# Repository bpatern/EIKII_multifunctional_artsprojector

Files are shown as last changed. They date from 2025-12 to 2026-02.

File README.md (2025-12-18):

**THE ORIGINAL GOAL**
**Make a 16mm film projector portable and playable like an instrument. Retrofit with a DC motor and LED lamp, controlled by ESP32 micro-controller.**
This project is part of [SPECTRAL Wandering Sounds and Images Seminar](https://www.mire-exp.org/evenement/spectral-wandering-sound-and-images/) in Nantes FR in 2023/2024, enabling film projection performances that explore itinerancy, nomadism, and adaptation to multiple environments.

----

Contents
======

---- 

 - [Bill of Materials (BOM)](https://www.filmlabs.org/wiki/en/meetings_projects/spectral/mire-wandering/wandering-16mmprojection/budget) (filmlabs.org) or [Google Sheets alternate](https://docs.google.com/spreadsheets/d/1z_asHddtIuv7a7RkZ9WCBqF81oMiJ9spwqh7lCQfW5E)
//self reminder to update w/ off the shelf parts and harvestable components
	
 - [Step-by-step Construction Guide](https://www.filmlabs.org/wiki/en/meetings_projects/spectral/mire-wandering/wandering-16mmprojection/construction_guide/start) for building and using the projector (filmlabs.org)
//break out into bulleted list with additional source for checking + installing LTC3780 and fan
//for non internal battery installations describe fitting of 20amp power supply
//describe optical printer dock and pros + cons
//describe stiffer motor mount construction from thick acrylic + pros and cons to using printed materials for this section

[openscad](https://github.com/z-l-p/film-projector-retrofit/tree/main/openscad)
----

 - Editable design files for 3D-printed parts (in OpenSCAD format)
 - new files are not made in openscad sorry

[projector\_code](https://github.com/bpatern/EIKII_multifunctional_artsprojector/tree/main/projector_code)
----

 - Code for the ESP32 micro-controller, raspberry Pi Pico 2W instruction parsing controller, and optical printer code that controls the projector (Arduino IDE)
 - optical printer functionality uses [Matt McWilliams' mCopy](https://github.com/sixteenmillimeter/mcopy) for sequencing. led support is enabled in sort of a hackneyed way, that currently only really works with my setup. id like to be able to have mCopy recognize the LED and its brightness control but I can't get mCopy and the led control scheme used in this code to shake hands. 

[stl](https://github.com/bpatern/EIKII_multifunctional_artsprojector/tree/main/stl)
----

 - Printable files for 3D-printed parts

closeup of lamp block
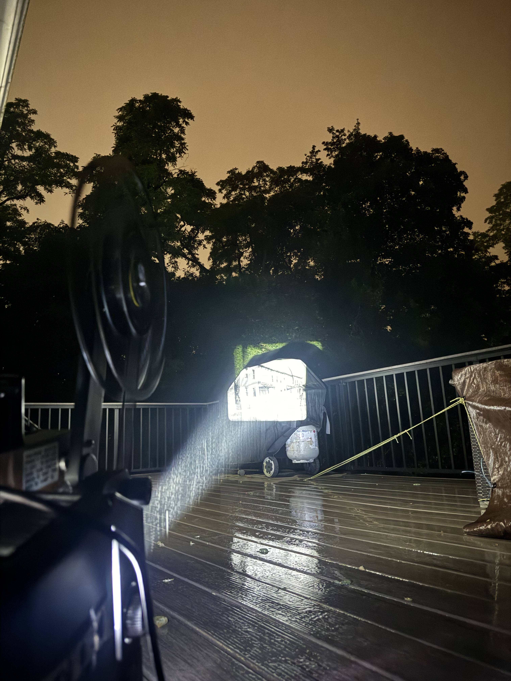
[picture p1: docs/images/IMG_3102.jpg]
projector in rain


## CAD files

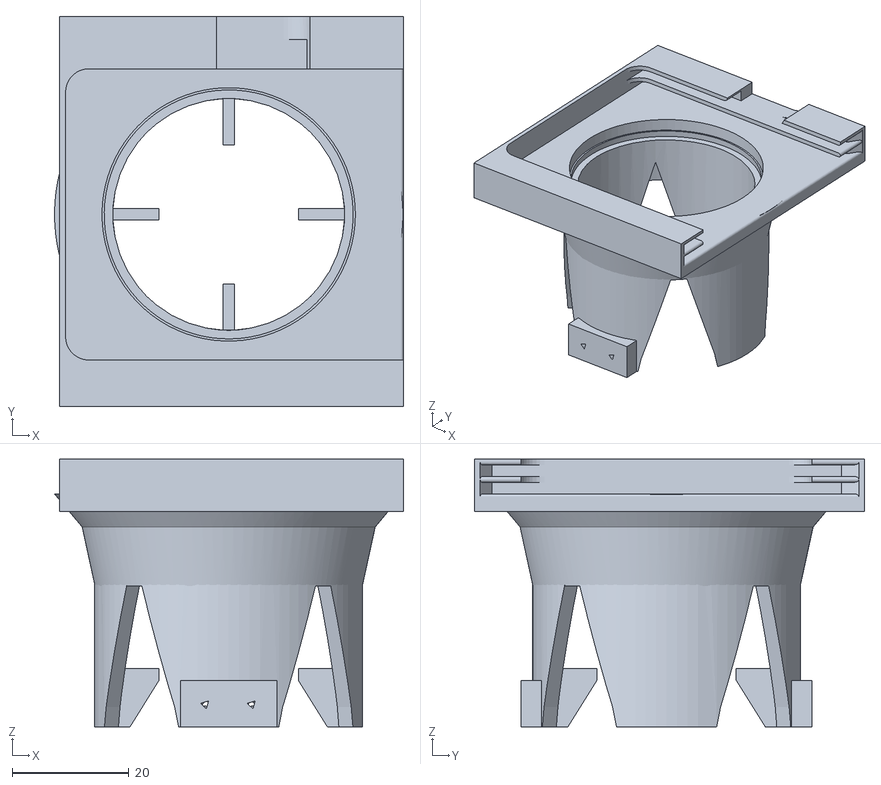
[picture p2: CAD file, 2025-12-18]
stl/led reflector holder for optical printer.stl
59.9 x 67.0 x 46.0

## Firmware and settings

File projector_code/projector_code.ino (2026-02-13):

//i've moved a lot around. biggest change i had to make was making certain variables global like those at the beginning of CalcFPS. if i didnt make this change i would get crashing if the projector was running for a Long Time. debug stated it was fetching a value before the value was even written. this is probably a result of additional tasks needing to happen during the main loop. splitting operations out to multicore would maybe help, or using the ESP32-s3 with additional SRAM

// ------------------------------------------
// SPECTRAL Wandering Sounds + Images Seminar
// ------------------------------------------
// Projector control software for ESP32 micro-controller
// On some 38pin ESP32 boards you need to press GPIO 0 [right] button each time you upload code. If so, solder 10uF cap between EN and GND to enable auto reset.
// Controlling Hobbywing "Quickrun Fusion SE" motor/ESC combo using ESP32 LEDC peripheral (using 16bit timer for extra resolution)
// Note: Hobbywing motor/esc needs to be programmed via "programming card" to disable braking, otherwise it will try to hold position when speed = 0
// (If you hack the ESC wiring according to our docs, you can program it with the ESCprogram() function instead of a programming card)
// "Digital shutter" is accomplished via AS5047 magnetic rotary encoder, setup via SPI registers and monitored via ABI quadrature pulses
// LED is dimmed via CC LED driver board with PWM input, driven by ESP32 LEDC (which causes slight PWM blinking artifacts at low brightness levels)
// Future option exists for current-controlled dimming (set LedDimMode=0): Perhaps a log taper digipot controlled via SPI? Probably can't dim below 20% though.


// TODO Nice but not essential:
// put UI vars in struct, in case we want to receive them from a remote ESP connected via radio
// if ESP32 Arduino core ever gets support for ledc output_invert method, we can simplify the ISR inverted condition

// Include the libraries
// NOTE: In 2023 this code was developed using the ESP32 Arduino core v2.0.9.
// When ESP32 Arduino core v3.x is released there will be breaking changes because LEDC setup will be different!
#include <AS5X47.h>              // https://github.com/adrien-legrand/AS5X47
#include <elapsedMillis.h>       // https://github.com/pfeerick/elapsedMillis
#include <Ramp.h>                // https://github.com/siteswapjuggler/RAMP
#include <SimpleKalmanFilter.h>  // https://github.com/denyssene/SimpleKalmanFilter
#include <Button2.h>             // https://github.com/LennartHennigs/Button2
#include <Adafruit_NeoPixel.h>   // https://github.com/adafruit/Adafruit_NeoPixel

#include <FastInterruptEncoder.h>

#include <HardwareSerial.h>
#include "freertos/FreeRTOS.h"
#include "freertos/task.h"


// Uncomment ONE of these to load preset configurations from the matching files
#include "spectral_eiki.h"  // "Store projector-specific settings here"
//#include "spectral_p26.h" // "Store projector-specific settings here"



// Encoder
#define EncI 17   // encoder pulse Index (AS5047 sensor)
#define EncA 16   // encoder pulse A (AS5047 sensor)
#define EncB 4    // encoder pulse B (AS5047 sensor)
#define EncCSN 5  // encoder SPI CSN Pin (AS5047 sensor) - Library also reserves GPIO 18, 19, 23 for SPI

Encoder enc(EncA, EncB, FULLQUAD, 0);


// OUTPUT PINS //
#define escPin 22         // PWM output for ESC
#define escProgramPin 21  // serial output to program ESC (needs 10k resistor to 3.3v)
#define ledPin 2          // PWM output for LED (On 38pin HiLetGo ESP32 board, GPIO 2 is the built-in LED)
#define NeoPixelPin 15    // output pin for NeoPixel status LED(s)

// Simple Kalman Filter Library Setup
// see tuning advice here: https://www.mathworks.com/help/fusion/ug/tuning-kalman-filter-to-improve-state-estimation.html
// and this playlist: https://www.youtube.com/watch?v=CaCcOwJPytQ&list=PLX2gX-ftPVXU3oUFNATxGXY90AULiqnWT
float kalmanMEA = 2;    // "measurement noise estimate" (larger = we assmume there is more noise/jitter in input)
float kalmanQ = 0.010;  // "Process Noise" AKA "gain" (smaller = more smoothing but more latency)

SimpleKalmanFilter motPotKalman(kalmanMEA, kalmanMEA, kalmanQ);
SimpleKalmanFilter ledPotKalman(kalmanMEA, kalmanMEA, kalmanQ);

#if (enableSlewPots)
SimpleKalmanFilter motSlewPotKalman(kalmanMEA, kalmanMEA, kalmanQ);
SimpleKalmanFilter ledSlewPotKalman(kalmanMEA, kalmanMEA, kalmanQ);
#endif

#if (enableShutterPots)
SimpleKalmanFilter shutBladesPotKalman(kalmanMEA, kalmanMEA, kalmanQ);
SimpleKalmanFilter shutAnglePotKalman(kalmanMEA, kalmanMEA, kalmanQ);
#endif

// For the FPSreal averaging
const int FPSnumReadings = 3;       // how many FPS readings to average together
float FPSAvgArray[FPSnumReadings];  // the FPS readings array
int FPSAvgReadIndex = 0;            // the index of the current reading
float FPSAvgTotal = 0;              // total of all readings


#if (enableButtons)
// Bounce2 Library setup for buttons
Button2 buttonA;
Button2 buttonB;

bool buttonAstate = 0;
bool buttonBstate = 0;
#endif

int motExtSwitch = 0;
volatile int motModeMidi;

int ledSlewVal = 0;
int ledSlewValOld;
int ledSlewMin = 0;      // the minumum slew value when knob is turned down (msec).
int ledSlewMax = 10000;  // the max slew value when knob is turned up (msec).

int motSlewVal = 0;
int motSlewValOld;
int motSlewMin = 0;      // the minumum slew value when knob is turned down (msec).
int motSlewMax = 10000;  // the max slew value when knob is turned up (msec).

int shutBladesPotVal;
int shutBladesVal;
int shutBladesValOld;
int shutAnglePotVal;
float shutAngleVal;
float shutAngleValOld;

volatile int as5047absAngle;





// Ramp library setup
rampInt motAvg;  // ramp object for motor speed slewing
rampInt ledAvg;  // ramp object for LED brightness slewing


#if (enableStatusLed)
  // NeoPixel library setup
#define NUMPIXELS 1  // How many NeoPixels are attached?

Adafruit_NeoPixel pixels(NUMPIXELS, NeoPixelPin, NEO_RGB + NEO_KHZ800);
// last argument should match your LED type. Add together as needed:
//   NEO_KHZ800  800 KHz bitstream (most NeoPixel products w/WS2812 LEDs)
//   NEO_KHZ400  400 KHz (classic 'v1' (not v2) FLORA pixels, WS2811 drivers)
//   NEO_GRB     Pixels are wired for GRB bitstream (most NeoPixel products)
//   NEO_RGB     Pixels are wired for RGB bitstream (5mm LEDS, v1 FLORA pixels, not v2)
//   NEO_RGBW    Pixels are wired for RGBW bitstream (NeoPixel RGBW products)
#endif

// UI VARS (could also be updated by remote control in future. Put these in a struct for easier radiolib management?)
int motPotVal = 0;  // current value of Motor pot (not necessarily the current speed since we might be ramping toward this value)
int motPotFPS = 1;  // current requested FPS based on motPotVal and scaling
int motPotFPSOld = 0;
int ledPotVal = 0;  // current value of LED pot (not necessarily the current LED brightness since we might be fading or strobing)
int ledPotValOld;



// LED VARS //
int LedDimMode = 1;               // 0 = current-controlled dimming (NOT YET IMPLEMENTED!), 1 = PWM dimming
int LedInvert = 1;                // set to 1 to invert LED output signal so it's active-low (required by H6cc driver board)
int ledBright = 0;                // current brightness of LED (range depends on Res below. If we're ramping then this will differ from pot value)
float safeSpeedMult = 0.4;        // multiplier to use in "safe mode" to lower lamp brightness at low FPS
const int ledBrightRes = 12;      // bits of resolution for LED dimming
const int ledBrightFreq = 18000;  // PWM frequency (500Hz is published max for H6cc LED driver, 770Hz is closer to shutter segment period, 1000 seems to work best)
const int ledChannel = 0;         // ESP32 LEDC channel number. Pairs share settings (0/1, 2/3, 4/5...) so skip one to insure your settings work!

// MOTOR VARS We are using ESP32 LEDC to drive the RC motor ESC via 1000-2000uS PWM @50Hz (standard servo format)
int motMode = 0;               // motor run mode (-1, 0, 1)
int motModePrev = 0;           // previous motor run mode (-1, 0, 1)
int motSingle = 0;             // indicates that we're traveling in single frame mode
int motSinglePrev = 0;         // were we in single frame mode during the last loop?
int motSingleMinTime = 800;    // the minimum movement time (MS) for each single frame move
volatile int motModeReal = 0;  // Current running direction detected by encoder (-1, 1)
float motSpeedUS = 1500;       // speed of motor (in pulsewidth uS from 1000-2000)
const int motPWMRes = 16;      // bits of resolution for extra control (standard servo lib uses 10bit)

const int motPWMChannel = 2;              // ESP32 LEDC channel number. Pairs share settings (0/1, 2/3, 4/5...) so skip one to insure your settings work!
const int motPWMFreq = 50;                // PWM frequency (50Hz is standard for RC servo / ESC)
int motPWMPeriod = 1000000 / motPWMFreq;  // microseconds per pulse

// prototypes for ISR functions that will be defined in later code
// (prototype must be declared _before_ we attach interrupt because ESP32 requires "IRAM_ATTR" flag which breaks typical Arduino behavior)
void IRAM_ATTR pinChangeISR();
void IRAM_ATTR send_LEDC();

TaskHandle_t pcISR;
TaskHandle_t ledCshutter;

void pcISRCORE(void *pvparemeters) {
  Serial.print("Digital shutter is executing on core ");
  Serial.println(xPortGetCoreID());
  for (;;)
  {
  if (enableShutter) {
    attachInterrupt(EncA, pinChangeISR, CHANGE);
    attachInterrupt(EncB, pinChangeISR, CHANGE);

    if (enc.init()) {
      Serial.println("PWM Encoder GOOD");
    } else {
      Serial.println("PWM Encoder ERROR");
    }
  }
  vTaskDelete(pcISR);
  }
}

// Start connection to the sensor.
AS5X47 as5047(EncCSN);
// will be used to read data from the magnetic encoder
ReadDataFrame readDataFrame;
volatile bool shutterMap[countsPerFrame];  // array holding values for lamp state at each position of digital shutter
volatile bool shutterStateOld = 0;         // stores the on/off state of the shutter from previous encoder position
static byte abOld;                         // Initialize state
volatile int count;                        // current rotary count
int countOld;                              // old rotary count
volatile int EncIndexCount;                // How many times have the A or B pulses transitioned while index pulse has been high
int as5047MagOK = 0;                       // status of magnet near AS5047 sensor
int as5047MagOK_old = 0;

// Machine Status Variables
volatile long frame = 0;      // current frame number (frame counter)
long frameOld = 0;            // old frame number for encoder
long frameOldsingle = 0;      // old frame number for encoder
volatile float FPScount = 0;  // measured FPS, sourced from encoder counts (100 updates per frame)
volatile float FPSframe = 0;  // measured FPS, sourced from frame counts
float FPSreal = 0;            // non-volatile FPS, sourced from encoder counts at slow speeds and frame counts at high speeds
float FPSrealAvg = 0;         // non-volatile measured FPS after averaging for jitter reduction
float FPStarget = 0;          // requested FPS


//external communication variables and settings//
int sfRequest;
int runRequest;

int frameCountResetRequest;
int opticalPrinter = 0;
int opAlignment = 0;
int capFlag = 0;
int mCopyStatus = 0;
int pullDownPos = 20;
int scanFlag = 0;

//ext midi variables -- may use CC2 for optical printer
int musicMode = 0;
int CC1ProjSpeed;
int CC3ProjBright;
int CC2ProjBlades;
int moveStatus;
int MSFStatus;
int motSingleRun;
int recSpecs;

int receivedRecvdConfirm2;
int receivedRecvdConfirm;




//calcFPS variables. esp memory was dumping them before...
boolean newData = false;
const byte numChars = 32;
char receivedChars[numChars];
char tempChars[numChars];

volatile float myFPScount = FPScount;      // copy volatile FPS to nonvolatile variable so it's safe
volatile float myFPSframe = FPSframe;      // copy volatile FPS to nonvolatile variable so it's safe
volatile int myMotModeReal = motModeReal;  // copy volatile FPS to nonvolatile variable so it's safe

// Settings for HobbyWing Quicrun Fusion SE motor
#define ESC_WRITE_BIT_TIME_WIDTH 2500  // uSec length of each pulse ("2500" = 400 baud)
char ESC_settings[] = {
  0,                // RPM Throttle Matching enabled
  2,                // 3S LiPo cells
  0,                // "Low" battery cutoff threshold (Low / Med / High)
  1,                // 105C temp cutoff
  0,                // CCW rotation
  0,                // 6V BEC
  0,                // Drag brake force disabled
  3,                // Drag brake rate 5
  3,                // Max reverse force 100%
  5, 0, 4, 2, 0, 0  // extra bytes sniffed with logic analyzer, don't know what they're for
};
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
void loop() {
  as5047absAngle = map(as5047.readAngle(), 0, 360, 0, 100);

  // Time-critical IO happens in interrupts, but UI and decision-making happens at a slower pace in the main loop

  //update these functions @ 200 Hz
  //  if (timerFPS >= 5) {

  //    timerFPS = 0;
  //  }

  if (musicMode == 1) {
    midiParser();
    midiControlTakeover();
    readUI();
  }

  // update these functions @ 50 Hz
  if (timerUI >= 20) {
    as5047MagCheck();  // check for encoder magnet proximity
    calcFPS();
    if (musicMode == 0) {
      readUI();
    }
    updateMotor();
    updateLed();

    externalcontrol();
    // fixCount();






    timerUI = 0;
  }






  // These happen once per encoder count (only useful for debugging at slow speeds)
  if (countOld != count) {
    if (debugEncoder) {
      Serial.print("Frame: ");
      Serial.print(frame);
      Serial.print(", Frame Old: ");
      Serial.print(frameOldsingle);
      Serial.print(", Count: ");
      Serial.print(count);
      Serial.print(", Single: ");
      Serial.print(as5047.readAngle());
      Serial.print(", Lamp: ");
      Serial.print(shutterMap[count]);
      Serial.print(", Brightness: ");
      Serial.println(ledBright);
    }
    countOld = count;
  }

  // These happen once per frame (only useful for debugging)
  if (frameOld != frame) {
    if (debugFrames) {
      Serial.print("FRAME: ");
      Serial.print(frame);
      Serial.print(", FPSreal:");
      Serial.print(FPSreal);
      Serial.print(", FPS avg:");
      Serial.println(FPSrealAvg);
    }
    frameOld = frame;
  }
}

/////////////////////////////
//// ---> FUNCTIONS <--- ////
/////////////////////////////

// On interrupt, read input pins, compute new state, and adjust count


//updated rotary encoder reading to use esp32 hardware sections that look for pulse counts. this way pulses are noticed asynchronously rather than at the time of the interrupt.... the code within the interrupt wasn't really fast enough to both register a change and act on it. now rather than stopping when it notices something it acts more like a bear grabbing a fish from a stream for better or worse!
//if one were to use a PICO instead, use the PIO to achieve the same. 
//stm32 based stuff can use hw counters
void IRAM_ATTR pinChangeISR() {
  int encCountOld = enc.getTicks();

  enc.loop();

  if (digitalRead(EncI)) {
    EncIndexCount++;
  } else {
    EncIndexCount = 0;
  }
  //   //   // moving forwards ...
  if (enc.getTicks() > encCountOld) {
    //   //     // at index
    if (EncIndexCount == 2) {  // reset counter on 'middle" transition during index condition
      // count = 0;
      if (opticalPrinter == 0) {
        frame++;
      } else {
        frame--;
      }

      frame++;
      FPSframe = 1000000.0 / framePeriod;  // update FPS calc based on period between each frame
      framePeriod = 0;
    } else {
      // normal forwards count
      FPScount = 10000.0 / countPeriod;  // update FPS calc based on period between the 100 encoder counts
      countPeriod = 0;
      motModeReal = 1;  // mark that we're running forwards
    }

    count++;
    // wrap around
    if (count > countsPerFrame - 1) {
      count = 0;
    }
  } else {
    //   //     // moving backwards ...
    if (EncIndexCount == 2) {  // reset counter on 'middle" transition during index condition
      // at index
      // count = 0;
      if (opticalPrinter == 0) {
        frame--;
      } else {
        frame++;
      }
      FPSframe = 1000000.0 / framePeriod;  // update FPS calc based on period between each frame
      framePeriod = 0;
    } else {
      // normal backwards count
      FPScount = 10000.0 / countPeriod;  // update FPS calc based on period between the 100 encoder counts
      countPeriod = 0;
      motModeReal = -1;  // mark that we're running backwards
    }
    count--;
    // wrap around the circle instead of using negative steps
    if (count < 0) {
      count = countsPerFrame - 1;
    }
  }


  bool shutterState = shutterMap[count];  // copy shutter state to local variable in case it changes during the ISR execution (not possible?)
  if (shutterState != shutterStateOld) {  // only update LED if shutter state changes (not every step)
    send_LEDC();                          // actual update code is abstracted so it can be run in different contexts
  }
  shutterStateOld = shutterState;  // store to global variable for next time
}


// send info to the LEDC peripheral to update LED PWM (abstracted here because it's called from loop or ISR)
void IRAM_ATTR send_LEDC() {
  bool shutterState = shutterMap[count];  // copy shutter state to local variable in case it changes during the ISR execution (not possible?)

  if (LedDimMode) {  // PWM mode
    if (shutterState == 1 || enableShutter == 0) {
      // LED ON for this step of shutter OR shutter is disabled OR single framing, so LED is always on
      ledcSetup(ledChannel, ledBrightFreq, ledBrightRes);  // configure LED PWM function using LEDC channel
      ledcAttachPin(ledPin, ledChannel);                   // attach the LEDC channel to the GPIO to be controlled
      if (LedInvert) {
        ledcWrite(ledChannel, (1 << ledBrightRes) - ledBright);  // set lamp to desired brightness (inverted)
      } else {
        ledcWrite(ledChannel, ledBright);  // set lamp to desired brightness
      }


    } else if (shutterState == 0 && enableShutter == 1) {
      // LED OFF for this segment of shutter

      if (LedInvert) {
        // ledcDetachPin(ledPin);    // detach the LEDC channel to the GPIO to be controlled
        digitalWrite(ledPin, 1);  // send pin high to turn off LED
      } else {
        // digitalWrite(ledPin, 0);  // send pin high to turn off LED
        ledcDetachPin(ledPin);  // detach the LEDC channel to the GPIO to be controlled
      }
      ledcDetachPin(ledPin);
    }

  } else {
    if (LedInvert) {
      if (enableShutter) {
        digitalWrite(ledPin, !(shutterState));  // active low, using shutter
        ledcDetachPin(ledPin);
      } else {
        digitalWrite(ledPin, 0);  // active low, no shutter
      }
    } else {
      if (enableShutter) {
        digitalWrite(ledPin, shutterState);  // active high, using shutter
      } else {
        digitalWrite(ledPin, 1);  // active high, no shutter
      }
    }
  }
}


// check for encoder magnet proximity
void as5047MagCheck() {

  // read magnet AGC data from sensor registers
  readDataFrame = as5047.readRegister(DIAGAGC_REG);
  Diaagc diaagc;
  diaagc.raw = readDataFrame.values.data;
  //Serial.println(diaagc.values.magl);

  // check result for magnet errors and update global var
  if (diaagc.values.magh || diaagc.values.magl) {
    as5047MagOK = 0;
  } else {
    as5047MagOK = 1;
  }

  // take action if global var has changed
  if (as5047MagOK_old != as5047MagOK) {
    if (as5047MagOK) {
      Serial.println("Magnet OK");
      fixCount();  // magnet is back after loss, so fix the count using SPI
    } else {
      Serial.println("Magnet ERROR");
      fixCount();  // magnet is back after loss, so fix the count using SPI
    }
    as5047MagOK_old = as5047MagOK;
  }
}

// Correct the encoder count by asking the sensor for real value over SPI
// This is required during setup since interrupt counts are relative but SPI is absolute
// Also useful if we ever need to recover from a temporary loss of magnet position
void fixCount() {
  count = map(as5047.readAngle(), 0, 360, 0, 100);
  Serial.println("   (Updated count via SPI)");
}

// fill shutterMap array with boolean values to control LED state at each position of shutter rotation
void updateShutterMap(byte shutterBlades, float shutterAngle) { //move to core 0 with related interrupts
  //Serial.print("Update ShutterMap");
  // shutterBlades: number of virtual shutter blades (must be > 0)
  // shutterAngle: ratio between on/off for each shutter blade segment (0.5 = 180d)
  if (shutterBlades < 1) shutterBlades = 1;          // it would break if set to 0
  shutterAngle = constrain(shutterAngle, 0.0, 1.0);  // make sure it's 0-1
  for (int myBlade = 0; myBlade < shutterBlades; myBlade++) {
    int countOffset = myBlade * (countsPerFrame / shutterBlades);
    for (int myCount = 0; myCount < countsPerFrame / shutterBlades; myCount++) {
      if (myCount < countsPerFrame / shutterBlades * (1.0 - shutterAngle)) {
        shutterMap[myCount + countOffset] = 0;
      } else {
        shutterMap[myCount + countOffset] = 1;
      }
    }
  }
}

// Read user interface buttons and pots
// NOTE incurs 12ms blocking delay to help calm down crappy ADC between readings.
void readUI() {

  //if (onboardcontrol == 1) {

#if (enableButtons)
  buttonA.loop();  // update button managed by Bounce2 library
  buttonB.loop();  // update button managed by Bounce2 library
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

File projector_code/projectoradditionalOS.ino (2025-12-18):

#include <QuickStats.h>
#include <Arduino.h>
#include <U8g2lib.h>
#include <SoftwareSerial.h>
#include <elapsedMillis.h>
#include <Control_Surface.h>

#include <AH/Arduino-Wrapper.h>
#include <Adafruit_TinyUSB.h>
// #include <MIDIUSB.h>




#include "graphics.h"


#ifdef U8X8_HAVE_HW_I2C
#include <Wire.h>
#endif

#define OPTX 12
#define OPRX 13

#define midiRX 16

QuickStats stats;

elapsedMillis fwdProjTimer;
elapsedMillis timerUI;
elapsedMillis animationTimer;

// SerialPIO SoftSerial(OPTX, OPRX, 256);
SerialPIO midiConnection(SerialPIO::NOPIN, midiRX);

HardwareSerialMIDI_Interface midi(midiConnection, 31250);

// USBMIDI_Interface midi_usb;  //

// BidirectionalMIDI_Pipe pipes;



/////////////////////
//MIDI CONTROL CODE//
/////////////////////

int debugEnable = 1;  // for midi debugging! prints info to SMONITOR

#include "midiRef.h"


/////////////////////////


volatile int camFC = 0;

volatile int OPVariables = 4;
int projFWD;
int projREV;
int camFWD;
int camREV;
int shutterStatus;
int fwdFlag;


const byte numChars = 128;
char receivedChars[numChars];
char tempChars[numChars];

char receivedChars1[numChars];
char tempChars1[numChars];

int FRAMERATE = 0;
float SHUTTERANGLE = 0;
float LEDBRIGHT = 0;
int BLADECT = 0;
int machineStatus = 0;
int sfStatus = 0;
int frameCount = 0;
int mCopyStatus = 0;

int angle = 0;
int bladeCount = 0;
int ledPercentage = 0;

int sfUI = 0;
int sfDir;
unsigned long buttonPressedAt;


int motorcmd;
int sfcmd;
int resetFrameReq;


int pRun = 0;
int cRun = 0;


int opticalPrinter = 0;
int LEDBRIGHTop;
int opShutter = 0;
int opShutterSeq = 0;
unsigned long opShutterTimer = 0;
int pos;
int capperStatus = 0;



//external takeup for OP control//

#define takeup_1 14
#define takeup_2 15
#define sleep 10 






unsigned long serialTimer;

boolean newData = false;
boolean newData1 = false;

U8G2_SSD1306_128X32_UNIVISION_F_HW_I2C u8g2(U8G2_R2, /* reset=*/U8X8_PIN_NONE, /* clock=*/SCL, /* data=*/SDA);

typedef u8g2_uint_t u8g_uint_t;

int handshakeS;
int pD = 1;
int cD = 1;


void setup() {
  u8g2.begin();

  Serial2.setRX(9);
  Serial2.setTX(8);
  Serial2.begin(57600);
  // SoftSerial.begin(57600);
  Serial.begin(57600);

  Serial1.setRX(OPRX);
  Serial1.setTX(OPTX);
  Serial1.begin(57600);

  // midi | pipes | midi_usb;

  // midi_usb.begin();
  midi.begin();                 // Initialize the MIDI interface
  midi.setCallbacks(callback);  // Attach the custom callback


  // Wire1.setSDA(18);
  // Wire1.setSCL(19);
  // Wire1.begin();

      pinMode(takeup_1, OUTPUT);
  pinMode(takeup_2, OUTPUT);
   pinMode(sleep, OUTPUT);

  // Turn off motors - Initial state
  analogWrite(takeup_1, 500);
  digitalWrite(takeup_2, LOW);
   pinMode(sleep, HIGH);

}

void loop() {




  // if (calculateValue == 1) {
  //   midiMath();
  //   calculateValue = 0;
  // }
  // midi.update();  // Continuously handle MIDI input
  // midi_usb.update();
  // midiInterpreter();

  recvWithStartEndMarkers();

  if (newData == true) {
    strcpy(tempChars, receivedChars);
    parseData();
    //    showParsedData();
    newData = false;
  }

    graphics();
  auxiliary();
  


  // usbFWD();
  // if (timerUI >= 12) {




  if (cRun >= 0) {
    camera();
  }

  if (opticalPrinter == 1) {
  if (timerUI >= 1250 && pRun == 1 && pD == 1) {
    Serial.println("p");
    pRun = 0;
  } else if (timerUI >= 600 && pRun == 1 && pD == -1) {
    Serial.println("p");
    pRun = 0;
  }
  takeUp();
  }



  // if (debugEnable == 1) {
  //   debug();
  // }
}

void takeUp() {
  if (pRun == 1 && pD == 1) {
      pinMode(sleep, LOW);
  analogWrite(takeup_1, LOW);
  digitalWrite(takeup_2, 300);
  } else if (pRun == 0) {
    pinMode(sleep, HIGH);
  // analogWrite(MOT_A1_PIN, 300);
  // digitalWrite(MOT_A2_PIN, LOW);
  }

}


void camera() {
  if (cRun == 1) {
    Serial1.println('f');
    Serial1.flush();
    Serial.println("SENT");
    cRun = 0;
    timerUI = 0;
  } else if (cRun == 2) {
    Serial1.println('r');
    Serial1.flush();
    //        Serial.println("SENT");
    cRun = 0;
    timerUI = 0;
  }
}


void debug() {
  // Serial.print("channel ");
  // Serial.print(midiCurrentChannel);
  // Serial.print(" pitchBendValue ");
  // Serial.print(midiAdjustedPitchBendVal);
  // Serial.print(" current note ");
  // Serial.print(midiNotesPlayed[midiNotesPlayedIndex]);
  // Serial.print("note index");

  // Serial.print(midiNotesPlayed[1]);
  // Serial.print(midiNotesPlayed[2]);
  // Serial.print(midiNotesPlayed[3]);
  // Serial.print(midiNotesPlayed[4]);
  // Serial.print(midiNotesPlayed[5]);
  // Serial.print(midiNotesPlayed[6]);
  // Serial.print(midiNotesPlayed[7]);
  // Serial.print(midiNotesPlayed[8]);
  // Serial.print(midiNotesPlayed[9]);
  // Serial.print(midiNotesPlayed[10]);
  // Serial.print(averageKeysLoc);
  // Serial.print(" keys being pressed ");
  // Serial.println(midiCurrentKeys);
  // Serial.print("projector speed");
  // Serial.print(CC1ProjSpeed);
  // Serial.print(" projector blade count ");
  // Serial.print(CC2ProjBlades);
  // Serial.print(" projector brightness ");
  // Serial.print(CC3ProjBright);
  // Serial.print(" single frame status ");
  // Serial.print(MSFStatus);
  // Serial.print(" movement position ");
  // Serial.print(moveCMD);
  // Serial.print(" single frame timer count ");
  // Serial.println(SingleTimer);

  Serial.println(moveCMD);
  Serial.println(moveHalt);
}


//  timerUI = 0;


void midiMath() {
  //60 keys total, so certain figures have to be out of 60
  averageKeysLoc = stats.average(midiNotesPlayed, midiNotesPlayedIndex);

  highestNote = stats.maximum(midiNotesPlayed, midiNotesPlayedIndex);

  lowestNote = stats.minimum(midiNotesPlayed, midiNotesPlayedIndex);

  highestNoteAdj = (highestNote - 36) / 60;

  lowestNoteAdj = (lowestNote - 36) / 60;

  midiAdjustedPitchBendVal = map(currentPitchBendVal, 0, 16320, 0, 100);

  int x;

  int y;

  for (x = 0; x < shFlCount; x = x + 1) {
    if ((shFl[x]) == (midiNotesPlayed[midiNotesPlayedIndex])) {
      shFlKeysPlayed = 1;
    }
  }

  for (y = 0; y < naturalsCount; y = y + 1) {
    if ((naturals[y]) == (midiNotesPlayed[midiNotesPlayedIndex])) {
      naturalsKeysPlayed = 1;
    }
  }
}
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

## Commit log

2025-12-18 Add files via upload
    dunno how this works ? hopefully this doesn't change the original main branch im pulling from. idk bro
    [midiRef.h, projector_code.ino, projectoradditionalOS.ino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]
2025-12-18 Add files via upload
    moved some toggles from projector_code to here because I was getting lost looking for them. also I added led brightness constraints here and definitions for serial command receipt and sends. miau
2025-12-18 Add files via upload
    messy updates to main projector code. lots of additions for the provision of additional functionality like off boarding pretty much all of the parsing logic to a Pi Pico running close by. changes inc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
2025-12-18 asterisks to optical printer functionality; link to Matt McWilliams' mCopy
    Updated project links and added details about optical printer functionality.
2025-12-18 eiki collimation lens mount with filter holder
    [led reflector holder for optical printer.stl]
2025-12-18 Revise README with updated links and notes
    Updated links and clarified information about 3D-printed parts.
2026-02-13 move encoder monitoring to dedicated esp32 pulse counter
    also started moving certain tasks to CORE 0
